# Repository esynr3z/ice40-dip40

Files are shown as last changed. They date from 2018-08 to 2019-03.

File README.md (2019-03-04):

# iCE40 breakout board

Miniature FPGA development board with DIP40 gabarits

## Features

* Lattice iCE40UP5KSG48 (iCE40 Ultra, iCE40 UltraPlus compatible - see Notes)
* Size 17.78mm x 50.8mm (DIP40)
* 16 MHz external generator
* Input power voltage: 5V (USB Micro B)
* USB data lines routed to FPGA
* 8Mb SPI flash for programming
* 34 IO pins available (3.3V)
* CRESET push button and CDONE led
* User led and user push button
* RGB led connected to internal driver

## Board

**BOARD IS NOT TESTED YET**

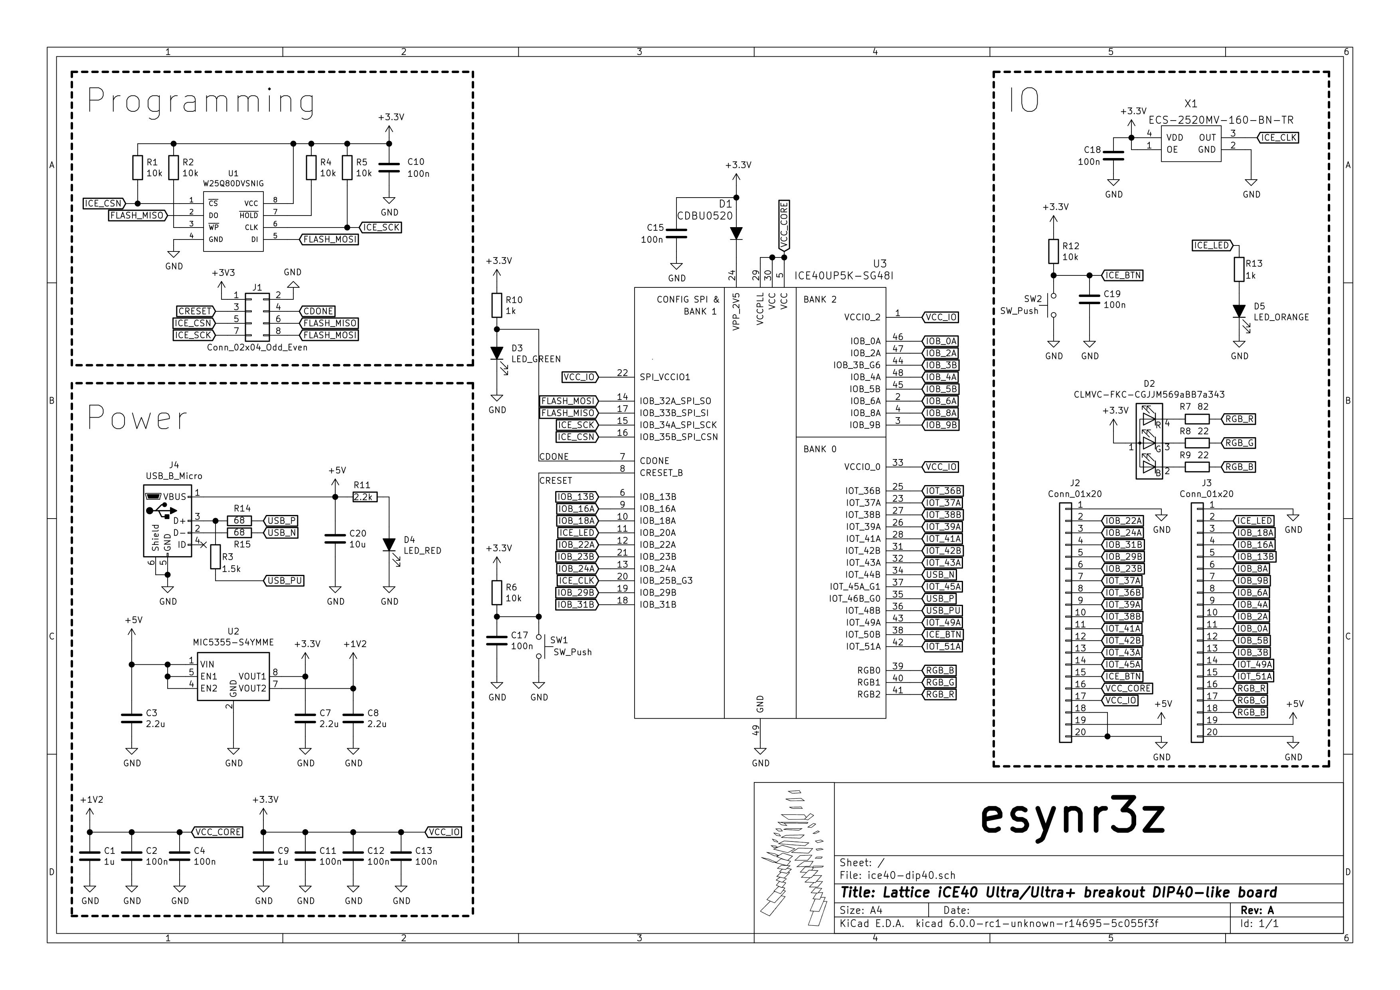
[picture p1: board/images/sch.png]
Schematic


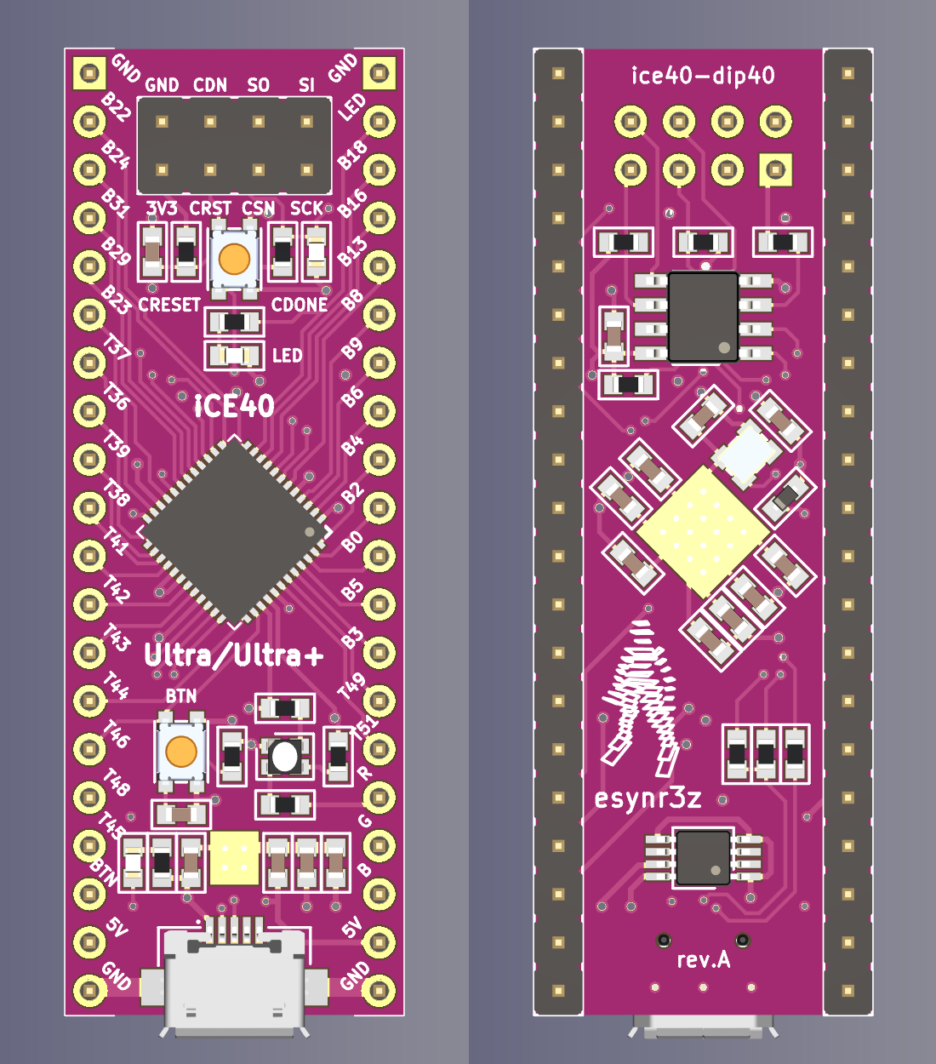
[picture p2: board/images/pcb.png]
PCB


## Notes

Board is routed for iCE40UP5KSG48 (iCE40 UltraPlus family), but list of supported FPGAs is quite wider:

* iCE40 Ultra - iCE5LP1KSG48, iCE5LP2KSG48, iCE5LP4KSG48
* iCE40 UltraPlus - iCE40UP3KSG48, iCE40UP5KSG48

There is only one difference in pinout between these families you should pay attention for:

| Func | iCE40 Ultra | iCE40 UltraPlus |
|-----:|---:|---:|
| RGB2 | 39 | 41 |
| RGB1 | 40 | 40 |
| RGB0 | 41 | 39 |

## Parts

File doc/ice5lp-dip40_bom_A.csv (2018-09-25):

Component | Description | Part | References | Value | Footprint | Quantity Per PCB | Datasheet
1 |  | Device_C | C2 C4 C10 C11 C12 C13 C15 C17 C18 C19 | 100n | C_0603 | 10 | ~
2 |  | Device_C | C20 | 10u | C_0603 | 1 | ~
3 |  | Device_C | C1 C9 | 1u | C_0603 | 2 | ~
4 |  | Device_C | C3 C7 C8 | 2.2u | C_0603 | 3 | ~
5 |  | esynr3z_DiodeRectifier_CDBU0520 | D1 | CDBU0520 | SOD-523F | 1 | lib_fp://www.comchiptech.com/cms/UserFiles/CDBU0520-RevA728099.pdf
6 |  | esynr3z_LED_CLMVC-FKC-CGJJM569aBB7a343 | D2 | CLMVC-FKC-CGJJM569aBB7a343 | LED_Cree-PLCC4_2x2mm_CW | 1 | ~
7 |  | Device_LED_ALT | D3 | LED_GREEN | LED_0603 | 1 | ~
8 |  | Device_LED_ALT | D5 | LED_ORANGE | LED_0603 | 1 | ~
9 |  | Device_LED_ALT | D4 | LED_RED | LED_0603 | 1 | ~
10 |  | Connector_Generic_Conn_01x20 | J2 J3 | Conn_01x20 | PinHeader_1x20_P2.54mm_Vertical | 2 | ~
11 |  | Connector_Generic_Conn_02x04_Odd_Even | J1 | Conn_02x04_Odd_Even | PinHeader_2x04_P2.54mm_Vertical | 1 | ~
12 |  | Connector_USB_B_Micro | J4 | USB_B_Micro | USB_Micro-B_Wurth_629105136821 | 1 | ~
13 |  | Device_R | R3 | 1.5k | R_0603 | 1 | ~
14 |  | Device_R | R1 R2 R4 R5 R6 R12 | 10k | R_0603 | 6 | ~
15 |  | Device_R | R10 R13 | 1k | R_0603 | 2 | ~
16 |  | Device_R | R11 | 2.2k | R_0603 | 1 | ~
17 |  | Device_R | R8 R9 | 22 | R_0603 | 2 | ~
18 |  | Device_R | R14 R15 | 68 | R_0603 | 2 | ~
19 |  | Device_R | R7 | 82 | R_0603 | 1 | ~
20 |  | Switch_SW_Push | SW1 SW2 | SW_Push | PTS830 | 2
21 |  | esynr3z_MemoryFlash_AT25D081-SSHD | U1 | AT25D081-SSHD | SOIC-8_3.9x4.9mm_P1.27mm | 1 | https://www.adestotech.com/wp-content/uploads/DS-AT25SF081_045.pdf
22 |  | esynr3z_FPGA_ICE5LP4K-SG48 | U3 | ICE5LP4K-SG48 | QFN-48-1EP_7x7mm_P0.5mm_EP5x5mm_ThermalVias | 1
23 |  | esynr3z_RegulatorLinear_MIC5355-S4YMME | U2 | MIC5355-S4YMME | MSOP-8-1EP_3x3mm_P0.65mm_EP2.54x2.8mm_ThermalVias | 1 | lib_fp://ww1.microchip.com/downloads/en/DeviceDoc/mic5355_6.pdf
24 |  | esynr3z_Oscillator_ECS-2520MV-XXX | X1 | ECS-2520MV-120-BN-TR | ECS-2520MV_4Pin_2.5x2.0mm | 1 | lib_fp://www.ecsxtal.com/store/pdf/ECS-2520MV.pdf
Component Groups: | 24
Component Count: | 46
Fitted Components: | 46
Number of PCBs: | 1
Total components: | 46
Schematic Version: | A
Schematic Date: | 2018-07-23
BoM Date: | Tue 25 Sep 2018 20:38:47 MSK
Schematic Source: | /home/esynr3z/MyRepos/ice5lp-dip40/ice5lp-dip40.sch
KiCad Version: | Eeschema 6.0.0-rc1-unknown-r13783-618182dc

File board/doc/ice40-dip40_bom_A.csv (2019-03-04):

Item | Qty | Reference(s) | Value | LibPart | Footprint | Datasheet | Lanufacturer | Manufacturer | Mouser
1 | 2 | C1, C9 | 1u | ice40-dip40:Device_C | lib_fp:C_0603 | ~
2 | 10 | C2, C4, C10, C11, C12, C13, C15, C17, C18, C19 | 100n | ice40-dip40:Device_C | lib_fp:C_0603 | ~
3 | 3 | C3, C7, C8 | 2.2u | ice40-dip40:Device_C | lib_fp:C_0603 | ~
4 | 1 | C20 | 10u | ice40-dip40:Device_C | lib_fp:C_0603 | ~
5 | 1 | D1 | CDBU0520 | ice40-dip40:esynr3z_DiodeRectifier_CDBU0520 | lib_fp:SOD-523F | lib_fp://www.comchiptech.com/cms/UserFiles/CDBU0520-RevA728099.pdf |  |  | 750-CDBU0520
6 | 1 | D2 | CLMVC-FKC-CGJJM569aBB7a343 | ice40-dip40:esynr3z_LED_CLMVC-FKC-CGJJM569aBB7a343 | lib_fp:LED_Cree-PLCC4_2x2mm_CW | ~ |  |  | 941-CLMVG569ABB7A343
7 | 1 | D3 | LED_GREEN | ice40-dip40:Device_LED_ALT | lib_fp:LED_0603 | ~
8 | 1 | D4 | LED_RED | ice40-dip40:Device_LED_ALT | lib_fp:LED_0603 | ~
9 | 1 | D5 | LED_ORANGE | ice40-dip40:Device_LED_ALT | lib_fp:LED_0603 | ~
10 | 1 | J1 | Conn_02x04_Odd_Even | ice40-dip40:Connector_Generic_Conn_02x04_Odd_Even | lib_fp:PinHeader_2x04_P2.54mm_Vertical | ~
11 | 2 | J2, J3 | Conn_01x20 | ice40-dip40:Connector_Generic_Conn_01x20 | lib_fp:PinHeader_1x20_P2.54mm_Vertical | ~
12 | 1 | J4 | USB_B_Micro | ice40-dip40:Connector_USB_B_Micro | lib_fp:USB_Micro-B_Wurth_629105136821 | ~ |  |  | 710-629105136821
13 | 6 | R1, R2, R4, R5, R6, R12 | 10k | ice40-dip40:Device_R | lib_fp:R_0603 | ~
14 | 1 | R3 | 1.5k | ice40-dip40:Device_R | lib_fp:R_0603 | ~
15 | 1 | R7 | 82 | ice40-dip40:Device_R | lib_fp:R_0603 | ~
16 | 2 | R8, R9 | 22 | ice40-dip40:Device_R | lib_fp:R_0603 | ~
17 | 2 | R10, R13 | 1k | ice40-dip40:Device_R | lib_fp:R_0603 | ~
18 | 1 | R11 | 2.2k | ice40-dip40:Device_R | lib_fp:R_0603 | ~
19 | 2 | R14, R15 | 68 | ice40-dip40:Device_R | lib_fp:R_0603 | ~
20 | 2 | SW1, SW2 | SW_Push | ice40-dip40:Switch_SW_Push | lib_fp:PTS830 |  |  |  | 611-PTS830GM140SMTR
21 | 1 | U1 | W25Q80DVSNIG | ice40-dip40:esynr3z_MemoryFlash_W25Q80DVSNIG | lib_fp:SOIC-8_3.9x4.9mm_P1.27mm | https://www.winbond.com/resource-files/w25q80dv_revg_07212015.pdf |  |  | 454-W25Q80DVSNIG
22 | 1 | U2 | MIC5355-S4YMME | ice40-dip40:esynr3z_RegulatorLinear_MIC5355-S4YMME | lib_fp:MSOP-8-1EP_3x3mm_P0.65mm_EP2.54x2.8mm_ThermalVias | lib_fp://ww1.microchip.com/downloads/en/DeviceDoc/mic5355_6.pdf |  |  | 998-MIC5355-S4YMME
23 | 1 | U3 | ICE40UP5K-SG48I | ice40-dip40:esynr3z_FPGA_ICE40UP5K-SG48I | lib_fp:QFN-48-1EP_7x7mm_P0.5mm_EP5x5mm_ThermalVias |  | Lattice | Lattice | 842-ICE40UP5K-SG48I
24 | 1 | X1 | ECS-2520MV-160-BN-TR | ice40-dip40:esynr3z_Oscillator_ECS-2520MV-XXX | lib_fp:ECS-2520MV_4Pin_2.5x2.0mm | lib_fp://www.ecsxtal.com/store/pdf/ECS-2520MV.pdf |  |  | 520-2520MV-160-CNT

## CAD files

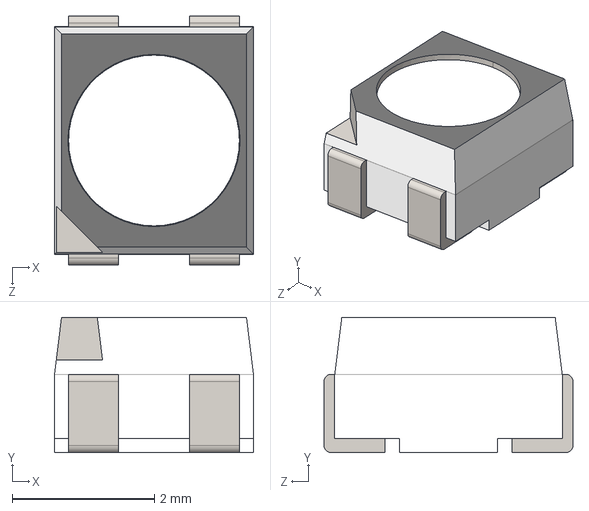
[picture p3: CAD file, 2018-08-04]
board/3d_models/LED_Cree-PLCC4_2x2mm_CW.step
2.80 x 1.90 x 3.50 mm

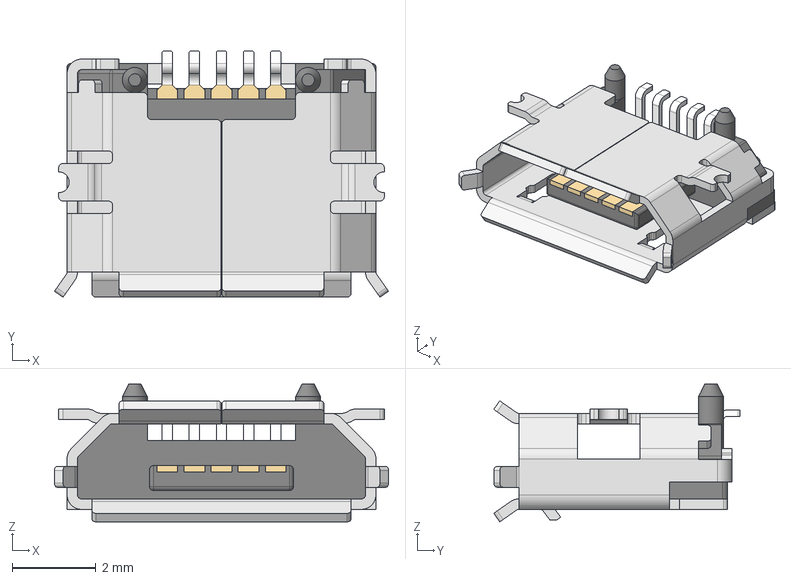
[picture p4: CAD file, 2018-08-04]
board/3d_models/USB_Micro-B_Wurth_629105136821.stp
8.00 x 5.90 x 3.30 mm
Shielding
Insulator
Pin x 5

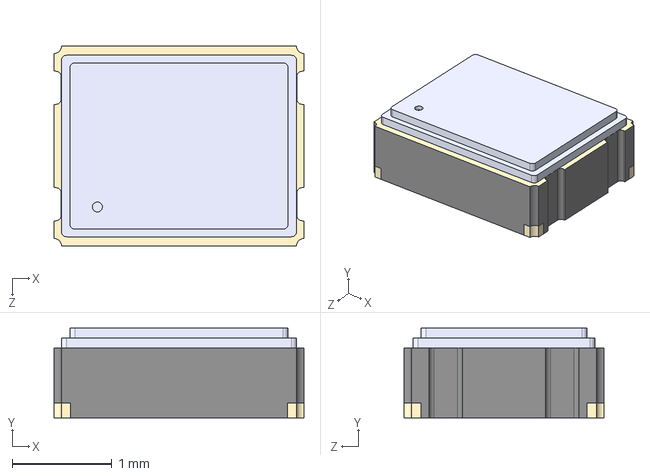
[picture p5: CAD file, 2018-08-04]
board/3d_models/ECS-2520MV_4Pin_2.5x2.0mm.STEP
2.50 x 0.9 x 2.00 mm

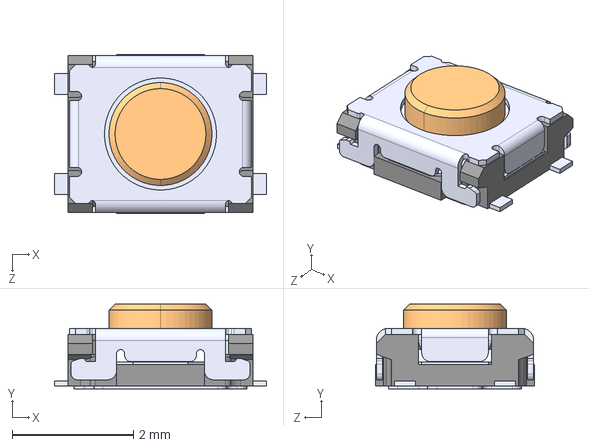
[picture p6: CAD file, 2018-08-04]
board/3d_models/PTS830GM140SMTRLFS.stp
3.50 x 1.40 x 2.62 mm

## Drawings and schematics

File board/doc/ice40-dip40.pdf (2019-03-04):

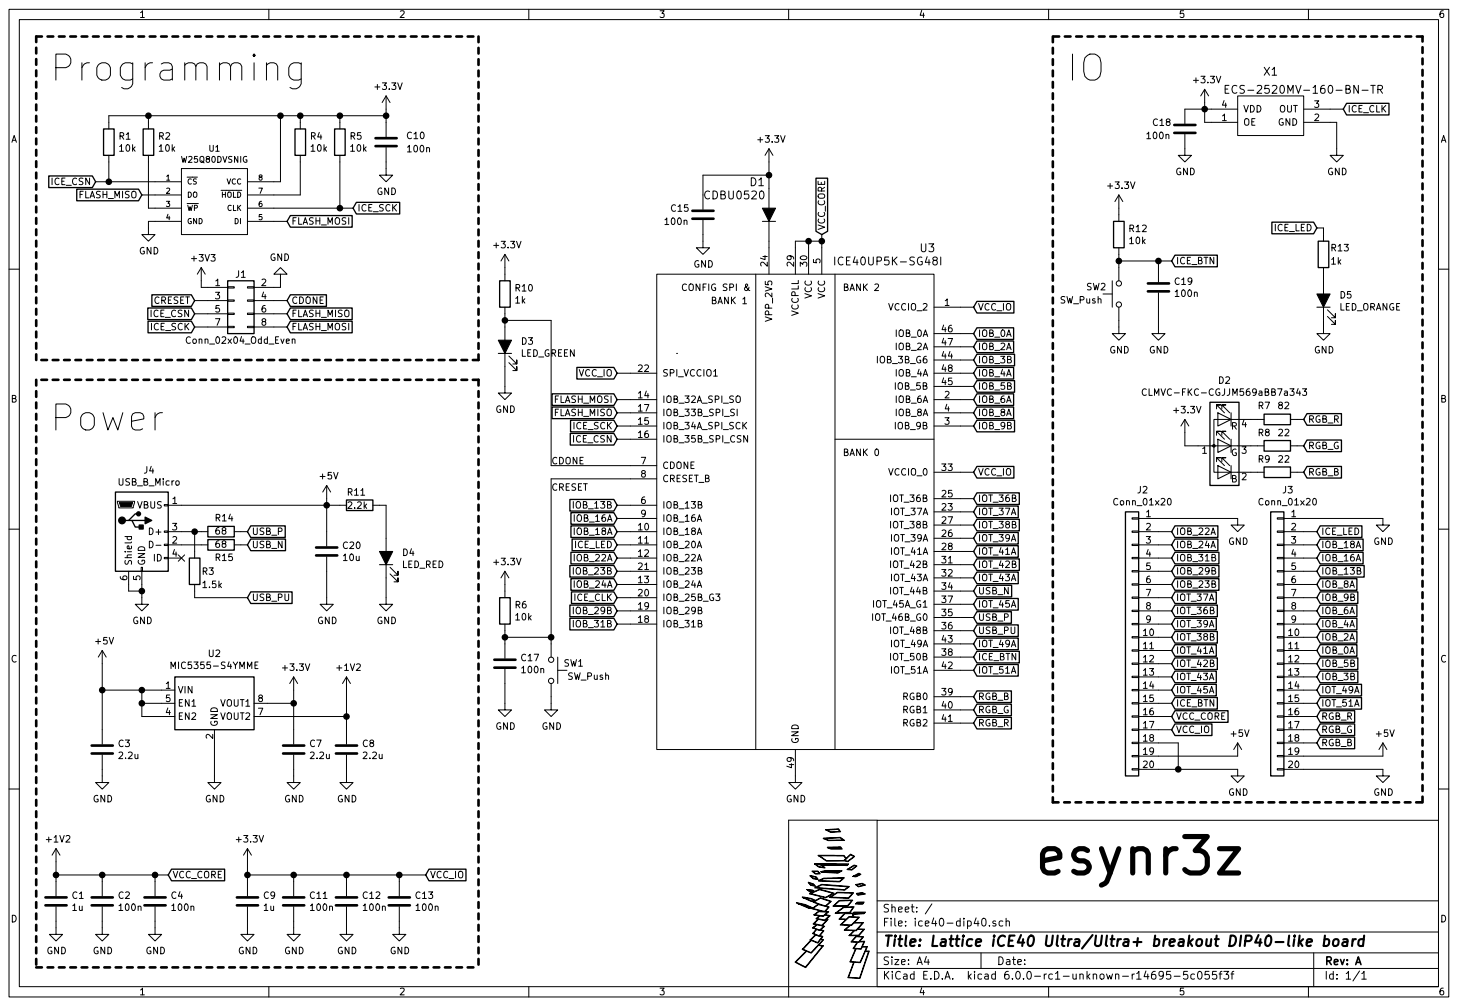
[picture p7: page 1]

J3 Conn_01x20 IO
File: ice40-dip40.sch Sheet: / GND VCC_CORE

Id: 1/1 Title: Lattice iCE40 Ultra/Ultra+ breakout DIP40-like board

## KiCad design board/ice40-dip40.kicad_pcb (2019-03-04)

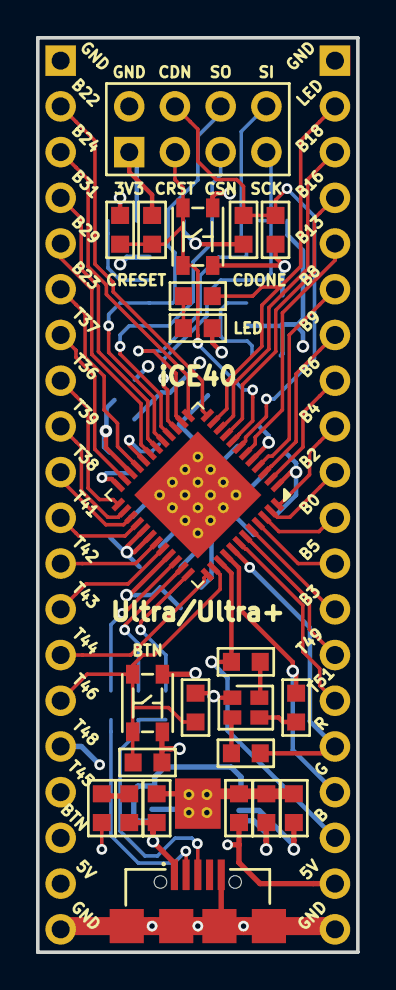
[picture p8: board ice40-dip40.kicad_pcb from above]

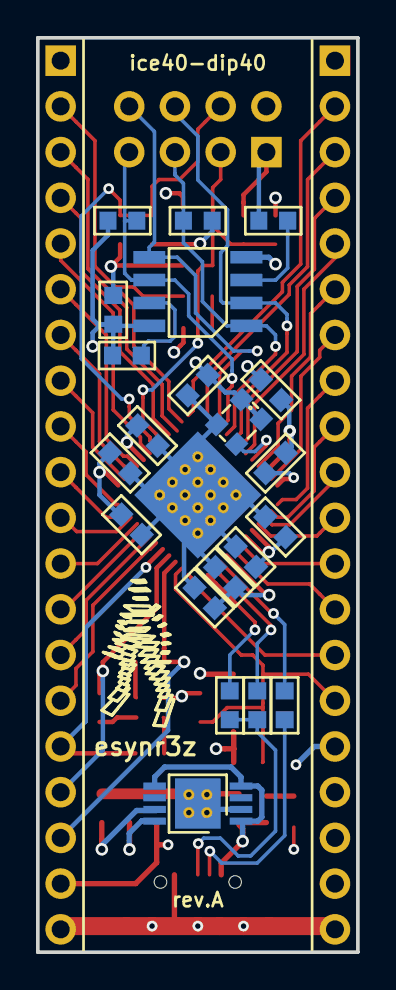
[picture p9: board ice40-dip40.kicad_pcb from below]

Board: 4 copper layers, 17.8 x 50.8 mm, 46 parts (23 on the bottom side), 55 nets.

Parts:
C1, C9: 1u; C_0603
C2, C4, C10, C11, C12, C13, C15, C17, C18, C19: 100n; C_0603
C3, C7, C8: 2.2u; C_0603
C20: 10u; C_0603
D1: CDBU0520; SOD-523F
D2: CLMVC-FKC-CGJJM569aBB7a343; LED_Cree-PLCC4_2x2mm_CW
D3: LED_GREEN; LED_0603
D4: LED_RED; LED_0603
D5: LED_ORANGE; LED_0603
J1: Conn_02x04_Odd_Even; PinHeader_2x04_P2.54mm_Vertical
J2, J3: Conn_01x20; PinHeader_1x20_P2.54mm_Vertical
J4: USB_B_Micro; USB_Micro-B_Wurth_629105136821
R1, R2, R4, R5, R6, R12: 10k; R_0603
R3: 1.5k; R_0603
R7: 82; R_0603
R8, R9: 22; R_0603
R10, R13: 1k; R_0603
R11: 2.2k; R_0603
R14, R15: 68; R_0603
SW1, SW2: SW_Push; PTS830
U1: W25Q80DVSNIG; SOIC-8_3.9x4.9mm_P1.27mm
U2: MIC5355-S4YMME; MSOP-8-1EP_3x3mm_P0.65mm_EP2.54x2.8mm_ThermalVias
U3: ICE40UP5K-SG48I; QFN-48-1EP_7x7mm_P0.5mm_EP5x5mm_ThermalVias
X1: ECS-2520MV-160-BN-TR; ECS-2520MV_4Pin_2.5x2.0mm

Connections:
+5V: C3.1, C20.1, J2.19, J3.19, J4.1, R11.2, U2.1, U2.4, U2.5
CDONE: D3.2, J1.4, R10.2, U3.7
CRESET: C17.1, J1.3, R6.2, SW1.2, U3.8
FLASH_MISO: J1.6, U1.2, U3.17
FLASH_MOSI: J1.8, U1.5, U3.14
GND: C1.2, C2.2, C3.2, C4.2, C7.2, C8.2, C9.2, C10.2, C11.2, C12.2, C13.2, C15.2, C17.2, C18.2, C19.2, C20.2, D3.1, D4.1, D5.1, J1.2, J2.1, J2.18, J2.20, J3.1, J3.20, J4.5, J4.6, SW1.1, SW2.1, U1.4, U2.2, U2.9, U3.49, X1.2
ICE_BTN: C19.1, J2.15, R12.2, SW2.2, U3.38
ICE_CLK: U3.20, X1.3
ICE_CSN: J1.5, R1.2, U1.1, U3.16
ICE_LED: J3.2, R13.1, U3.11
ICE_SCK: J1.7, R5.2, U1.6, U3.15
IOB_0A: J3.11, U3.46
IOB_2A: J3.10, U3.47
IOB_3B: J3.13, U3.44
IOB_4A: J3.9, U3.48
IOB_5B: J3.12, U3.45
IOB_6A: J3.8, U3.2
IOB_8A: J3.6, U3.4
IOB_9B: J3.7, U3.3
IOB_13B: J3.5, U3.6
IOB_16A: J3.4, U3.9
IOB_18A: J3.3, U3.10
IOB_22A: J2.2, U3.12
IOB_23B: J2.6, U3.21
IOB_24A: J2.3, U3.13
IOB_29B: J2.5, U3.19
IOB_31B: J2.4, U3.18
IOT_36B: J2.8, U3.25
IOT_37A: J2.7, U3.23
IOT_38B: J2.10, U3.27
IOT_39A: J2.9, U3.26
IOT_41A: J2.11, U3.28
IOT_42B: J2.12, U3.31
IOT_43A: J2.13, U3.32
IOT_45A: J2.14, U3.37
IOT_49A: J3.14, U3.43
IOT_51A: J3.15, U3.42
unnamed: D1.1, U3.24
unnamed: D2.2, R9.2
unnamed: D2.3, R8.2
unnamed: D2.4, R7.1
unnamed: D4.2, R11.1
unnamed: D5.2, R13.2
unnamed: J4.2, R15.1
unnamed: J4.3, R3.1, R14.1
unnamed: R2.2, U1.3
unnamed: R4.2, U1.7
RGB_B: J3.18, R9.1, U3.39
RGB_G: J3.17, R8.1, U3.40
RGB_R: J3.16, R7.2, U3.41
USB_N: R15.2, U3.34
USB_P: R14.2, U3.35
USB_PU: R3.2, U3.36
VCC_CORE: C1.1, C2.1, C4.1, C8.1, J2.16, U2.7, U3.5, U3.29, U3.30
VCC_IO: C7.1, C9.1, C10.1, C11.1, C12.1, C13.1, C15.1, C18.1, D1.2, D2.1, J1.1, J2.17, R1.1, R2.1, R4.1, R5.1, R6.1, R10.1, R12.1, U1.8, U2.8, U3.1, U3.22, U3.33, X1.1, X1.4

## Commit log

2018-07-10 Init repo
    [bb-ice5lp.kicad_pcb, bb-ice5lp.sch]
2018-07-13 Project name change
    [bb-ice5lp.sch, ice5lp-dip40.kicad_pcb, ice5lp-dip40.sch]
2018-07-13 Place all components on schematic
    [ice5lp-dip40.sch]
2018-07-13 Try to place biggest footprint on board
    [ice5lp-dip40.kicad_pcb]
2018-07-14 Add RGB LED and assign some FPGA IO to pin headers
    [ice5lp-dip40.kicad_pcb, ice5lp-dip40.sch]
2018-07-15 Add oscillator
    [ice5lp-dip40.kicad_pcb, ice5lp-dip40.sch]
2018-07-15 Add USB connector
    [ice5lp-dip40.kicad_pcb, ice5lp-dip40.sch]
2018-07-16 Add footprints to some symbols and trace pin headers and buttons
    [ice5lp-dip40.kicad_pcb, ice5lp-dip40.sch]
2018-07-17 Update footprints
    [ice5lp-dip40.kicad_pcb, ice5lp-dip40.sch]
2018-07-18 Place and trace all main components
    [ice5lp-dip40.kicad_pcb, ice5lp-dip40.sch]
2018-07-19 Place some caps
    [ice5lp-dip40.kicad_pcb, ice5lp-dip40.sch]
2018-07-23 Beautify schematic and place all components on PCB
    [ice5lp-dip40.kicad_pcb, ice5lp-dip40.sch]
2018-07-23 Fix some DRC errors on PCB
    [ice5lp-dip40.kicad_pcb]
2018-07-23 Add 2 inner layers and route power
    [ice5lp-dip40.kicad_pcb]
2018-07-23 Increase power tracks width
    [ice5lp-dip40.kicad_pcb]
2018-07-24 Beautify Silk and Fab layers
    [ice5lp-dip40.kicad_pcb]
2018-07-25 Add logo and final Silk edits
    [ice5lp-dip40.kicad_pcb]
2018-07-26 Some minor pcb fixes
    [ice5lp-dip40.kicad_pcb]
2018-07-26 Make footprints local
    [ice5lp-dip40.sch]
2018-08-04 Fix 3d model paths in project footprints
2018-08-04 Update to kicad 6.0.0-rc1
    [ice5lp-dip40.kicad_pcb]
2018-08-04 Archive project 3d models
    [ECS-2520MV_4Pin_2.5x2.0mm.STEP, LED_Cree-PLCC4_2x2mm_CW.step, PTS830GM140SMTRLFS.stp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]
2018-08-04 Make symbols project local
    [ice5lp-dip40.sch]
2018-09-21 Replace 1Mb flash with 8Mb one
    [ice5lp-dip40.kicad_pcb, ice5lp-dip40.sch]
2018-09-21 Update docs
    [ice5lp-dip40_bom_v1.0.csv]
2018-09-23 Trace USB data lines into fpga
    [ice5lp-dip40.kicad_pcb, ice5lp-dip40.sch]
2018-09-25 Update docs and generator info
    [ice5lp-dip40.kicad_pcb, ice5lp-dip40.sch, ice5lp-dip40_bom_A.csv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]
2018-09-25 Update doc
    [ice5lp-dip40.sch]
2018-09-30 Add info about other fpga supported
    [ice5lp-dip40.kicad_pcb]
2018-09-30 Project rename
    [ice40-dip40.kicad_pcb, ice40-dip40.sch, ice40-dip40_bom_A.csv]
2018-09-30 Add schematic image to readme
2018-09-30 Upgrade repo structure
    [ECS-2520MV_4Pin_2.5x2.0mm.STEP, LED_Cree-PLCC4_2x2mm_CW.step, PTS830GM140SMTRLFS.stp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]
2019-03-04 Update fpga, flash and oscillator
    [ice40-dip40.kicad_pcb, ice40-dip40.sch, ice40-dip40_bom_A.csv]
2019-03-04 Add mouser no and update all docs
    [ice40-dip40.sch, ice40-dip40_bom_A.csv]
